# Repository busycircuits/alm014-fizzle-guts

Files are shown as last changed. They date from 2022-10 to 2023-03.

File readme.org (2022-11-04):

* ALM014 FIZZLE GUTS

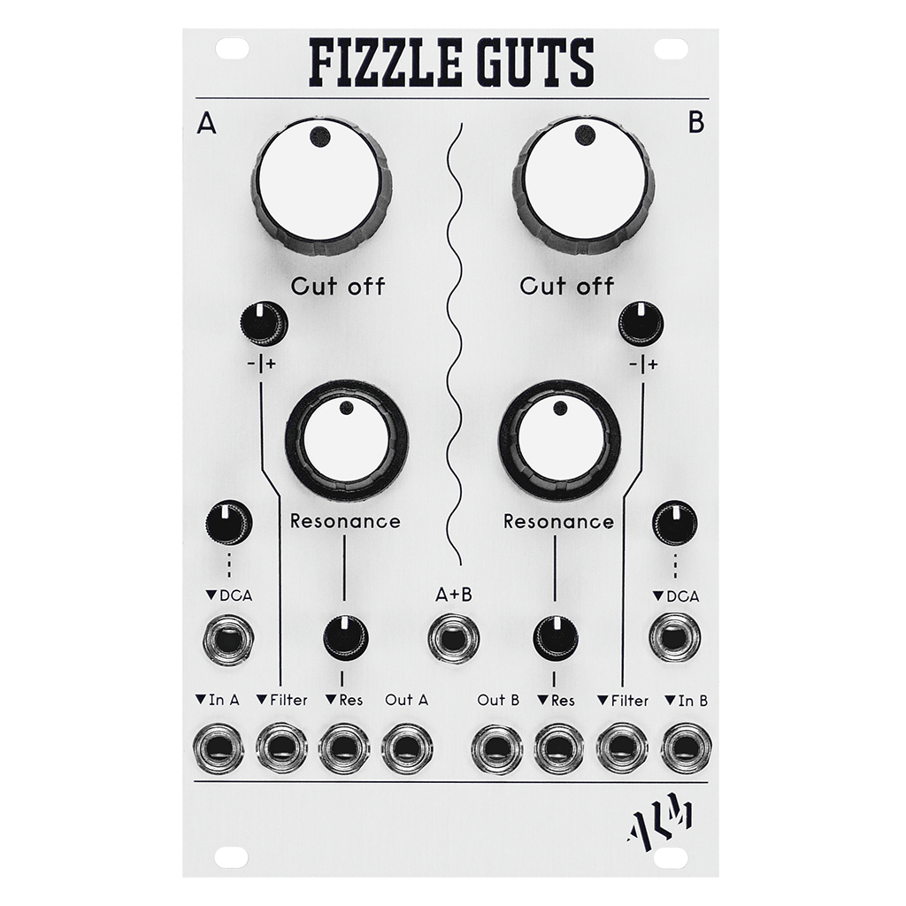
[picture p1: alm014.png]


** Introduction

The ALM Busy Circuits 'Fizzle guts' is a Eurorack dual low pass filter
and VCA that uses a 'donor' filter MB87186 chip from a Casio FZ1
sampler. It was originally designed in 2014 as a fun side project and
only approx 30 of the original units were made. With no plans to make
any more, we have open sourced the pcb design files (eagle), avr
microcontroller code and a basic panel design so others can make there
own and add customisations and/or improvements.

A built module features two filter cores A & B with voltage and direct
controlled resonance and cut off as well as a 'DCA' (a digital
controlled vca). There is also a mix output. Expect a weird murky
sounding filter which can squeek and blip when modulated but can
really squelch up nice.

You will need a donor 'MB87186' IC desolded from a real FZ1 or FZ1M
synth. They each contain 4 and the IC is usually marked 'FM1' with a
date code below. The IC then connects to the DIL socket on the rear of
the module.

For more information on the MB87186 (and from what much of the code
was based on) see http://www.buchty.net/casio/dcf.html

*PLEASE NOTE EVERYTHING IS PROVIDED AS IS. WE ARE UNABLE PROVIDE ANY SUPPORT TO ANYONE ATTEMPTING TO USE THESE FILES*

** Building and flashing the firmware

You'll need a basic 'usbtiny' AVR programmer.

You'll need to install avr-gcc and avrdude.

/(On mac using brew..)/
#+BEGIN_SRC
brew tap osx-cross/avr
brew install avr-gcc
brew install avrdude
#+END_SRC

Type 'make' in the firmare/ directory to compile the source code and
then run './flash.sh' (with your programmer connected) to program the
Fizzle.

** License

Code: MIT license.

Hardware: cc-by-sa-3.0

** Guidelines for derivative works

*ALM is a registered trademark.*

The name "ALM" should not be used on any of the derivative works you create from these files.

We kindly ask to do not name any derivatives 'FIZZLE GUTS' but give it a new name.

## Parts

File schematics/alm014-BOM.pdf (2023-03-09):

### FZ-FILTER-REV003 Passives + IC’s BOM

Qty | Parts | Value | Device | Package | Description | MF
1 | R38 | 1M | RESISTOR0603 | R0603
14 | R1, R3, R7, R10, R12, R14, R22, R32, R33, R34, R36, R46, R9, R16 | 100K | RESISTOR0603 | R0603
15 | R15, R17, R18, R19, R20, R23, R25, R27, R30, R35, R53, R39, R11, R29, R31 | 49.9k | RESISTOR0603 | R0603
4 | R6, R48, R50, R51 | 33K | RESISTOR0603 | R0603
12 | R2, R4, R5, R21, R28, R42, R45, R47, R40, R41, R43, R44 | 10K | RESISTOR0603 | R0603
3 | R8, R13, R49 | 1K | RESISTOR0603 | R0603
2 | R26, R37 | 2.2K | RESISTOR0603 | R0603
13 | C3, C7, C8, C13, C14, C15, C17, C18, C22, C28, C29, C31, C41 | 100n | CAPACITOR0603 | C0603
4 | C11, C16, C23, C24 | 10n | CAPACITOR0603 | C0603
2 | C21, C9 | 1n | CAPACITOR0603 | C0603
2 | C6, C27 | 47pf | CAPACITOR0603 | C0603
2 | C19, C20 | 20pf | CAPACITOR0603 | C0603
5 | C1, C2, C5, C12, C26 | 10uf / 25V | CPOL-EUB | PANASONIC_B | POLARIZED CAPACITOR, European symbol | Panasonic EEEHA1E100WR (or equiv)
2 | C4, C25 | 1uf / 25V | CPOL-EUB | PANASONIC_B | POLARIZED CAPACITOR, European symbol | Panasonic EEE1HA010SR (or equiv)
2 | D3, D13 | BAT54S | BAT54S | SOT23 | Schottky Diodes | BAT45S
2 | D1, D2 | RS 301-906 | DIODESMB | SMB-DIODE | Diode | Vishay VS-MBRS130LTRPBF (or similar)
1 | QF1 | 3.58Mhz | | | 3.58Mhz Resonator | Murata CSTLS3M58G56-B0
5 | IC1, IC2, IC5, IC7, IC8 | TL072D | TL072D | SO08 | OP AMP | TL072
1 | IC3 | MCP6004 | MCP6004 | SO14 | OP AMP | MCP6004
1 | IC6 | ATMEGA644A | ATMEGA644A | TQFP44 | MCU | Mouser 556-ATMEGA644A-AU
1 | U1 | SN74LVC2G14DBV | SN74LVC2G14DBV | SOT23-6 | DUAL SCHMITT-TRIGGER INVERTER | Mouser 595-SN74LVC2G14DBVR
1 | U3 | 7805 | VREG-7805-DPAK2 | VREG-7805-DPAK2 | | Mouser L7805CD2T-TR
1 | Y2 | 8M10AHC49T | 8M10AHC49T | HC49U | 20Mhz Crystal | Mouser 420-200-20-5PX

All caps at least 16v. All resistors 1% at least 0.1 watt

1

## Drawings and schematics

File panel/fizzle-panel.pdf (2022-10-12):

A B

# FIZZLE GUTS

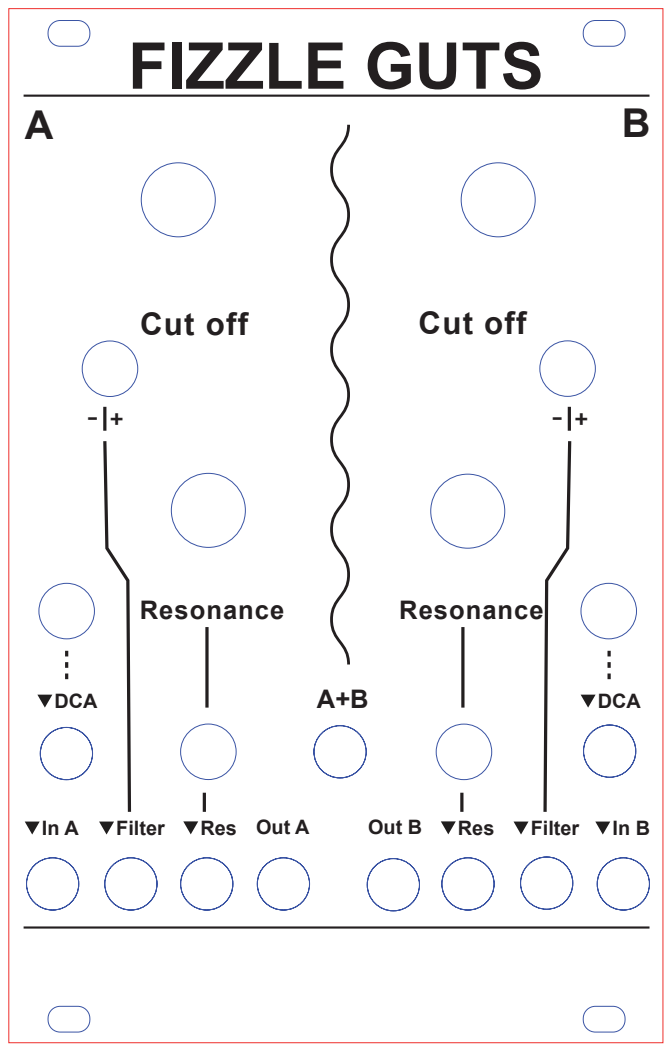
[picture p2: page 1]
Filter; Filter In B; DCA; Res Out A; Out B; Res; Cut off; Resonance

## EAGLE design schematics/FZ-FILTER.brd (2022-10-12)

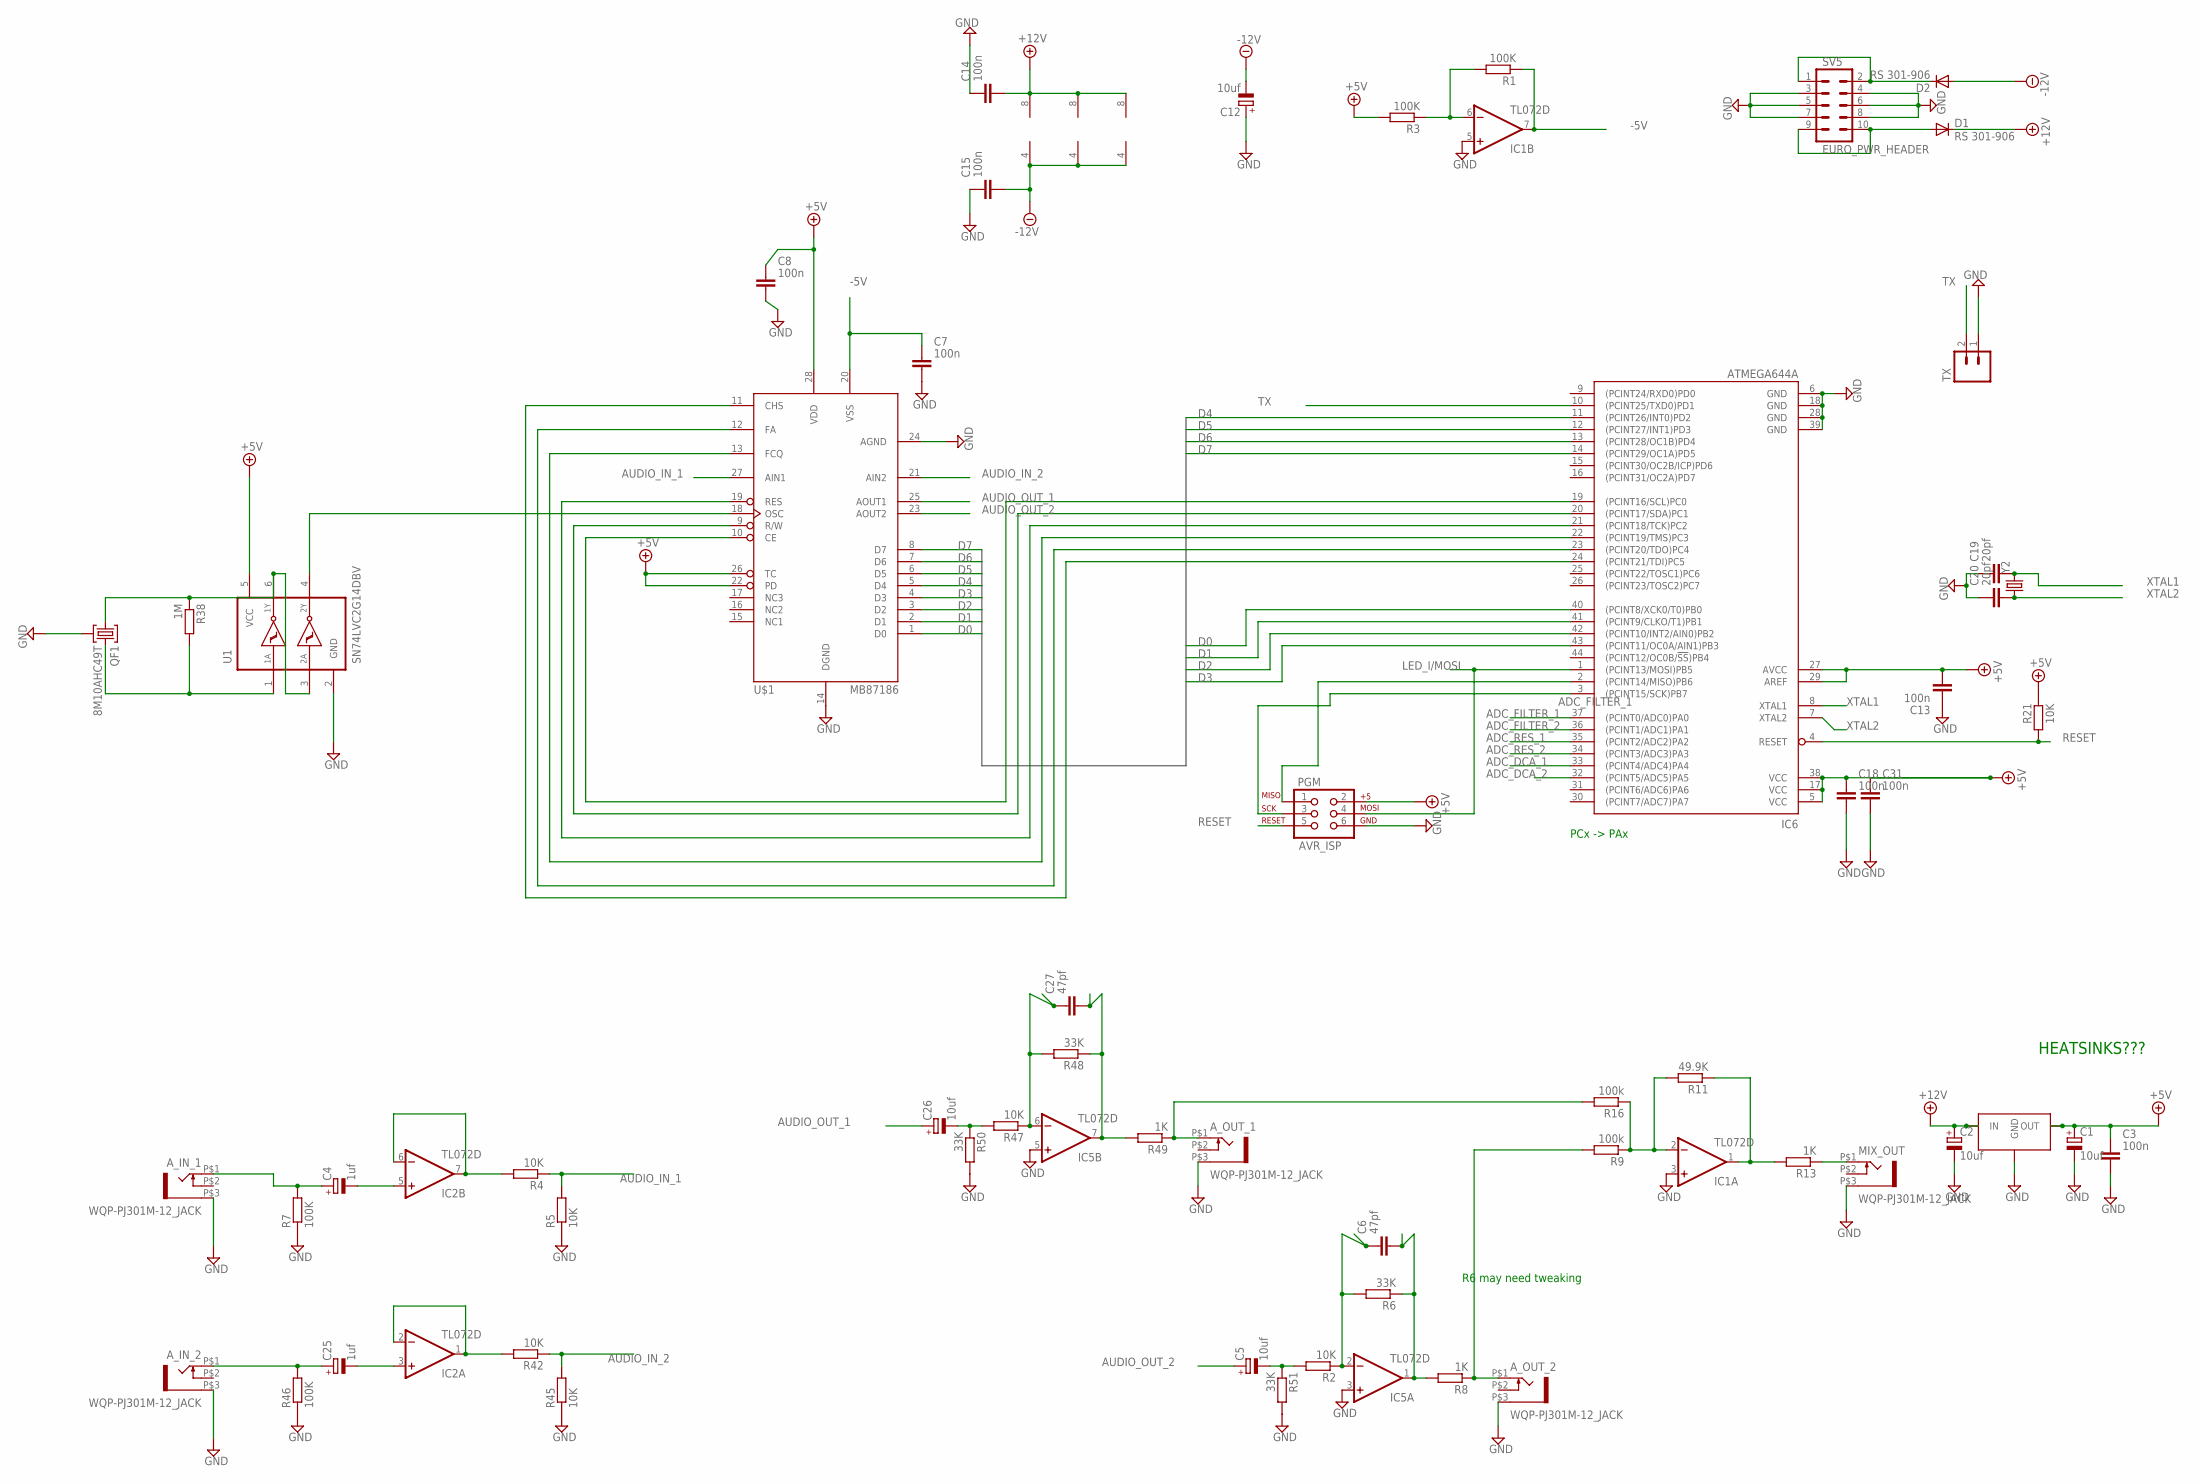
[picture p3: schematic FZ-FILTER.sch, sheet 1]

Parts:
A_IN_1, A_IN_2: WQP-PJ301M-12_JACK
A_OUT_1, A_OUT_2: WQP-PJ301M-12_JACK
C1, C2, C5, C12, C26: 10uf; PANASONIC_B
C3, C7, C8, C13, C14, C15, C18, C31: 100n; C0603
C4, C25: 1uf; PANASONIC_B
C6, C27: 47pf; C0603
C19, C20: 20pf; C0603
D1, D2: RS 301-906; SMB-DIODE
IC1, IC2, IC5: TL072D; SO08
IC6: ATMEGA644A; TQFP44
MIX_OUT: WQP-PJ301M-12_JACK
PGM: AVR_ISP; 2X3
QF1: 8M10AHC49T; HC49U
R1, R3, R7, R46: 100K; R0603
R2, R4, R5, R21, R42, R45, R47: 10K; R0603
R6, R48, R50, R51: 33K; R0603
R8, R13, R49: 1K; R0603
R9, R16: 100k; R0603
R11: 49.9K; R0603
R38: 1M; R0603
SV5: EURO_PWR_HEADER
TX: M02PTH; 1X02
U1: SN74LVC2G14DBV; SOT23-6
U3: 7805; VREG-7805-DPAK2
U$1: MB87186; DIP28
Y2: CRYSTALSMD; HC49UP

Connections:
+5V: C1.+, C3.1, C8.1, C13.2, C18.1, C31.1, IC6.5 (VCC), IC6.17 (VCC), IC6.27 (AVCC), IC6.29 (AREF), IC6.38 (VCC), PGM.2, R3.2, R21.2, U1.5 (VCC), U3.VOUT (OUT), U$1.22 (PD), U$1.26 (TC), U$1.28 (VDD); also elsewhere on the board
+12V: C2.+, C14.2, D1.C, IC1.8 (V+), IC2.8 (V+), IC5.8 (V+), U3.VIN (IN); also elsewhere on the board
-5V: C7.1, IC1.7 (OUT), R1.1, U$1.20 (VSS); also elsewhere on the board
-12V: C12.-, C15.2, D2.A, IC1.4 (V-), IC2.4 (V-), IC5.4 (V-); also elsewhere on the board
ADC_DCA_1: IC6.33 ((PCINT4/ADC4)PA4); also elsewhere on the board
ADC_DCA_2: IC6.32 ((PCINT5/ADC5)PA5); also elsewhere on the board
ADC_FILTER_1: IC6.37 ((PCINT0/ADC0)PA0); also elsewhere on the board
ADC_FILTER_2: IC6.36 ((PCINT1/ADC1)PA1); also elsewhere on the board
ADC_MISO: IC6.2 ((PCINT14/MISO)PB6), PGM.1
ADC_RES_1: IC6.35 ((PCINT2/ADC2)PA2); also elsewhere on the board
ADC_RES_2: IC6.34 ((PCINT3/ADC3)PA3); also elsewhere on the board
ADC_SCK: IC6.3 ((PCINT15/SCK)PB7), PGM.3
AUDIO_IN_1: R4.1, R5.2, U$1.27 (AIN1)
AUDIO_IN_2: R42.1, R45.2, U$1.21 (AIN2)
AUDIO_OUT_1: C26.+, U$1.25 (AOUT1)
AUDIO_OUT_2: C5.+, U$1.23 (AOUT2)
D0: IC6.40 ((PCINT8/XCK0/T0)PB0), U$1.1 (D0)
D1: IC6.41 ((PCINT9/CLKO/T1)PB1), U$1.2 (D1)
D2: IC6.42 ((PCINT10/INT2/AIN0)PB2), U$1.3 (D2)
D3: IC6.43 ((PCINT11/OC0A/AIN1)PB3), U$1.4 (D3)
D4: IC6.11 ((PCINT26/INT0)PD2), U$1.5 (D4)
D5: IC6.12 ((PCINT27/INT1)PD3), U$1.6 (D5)
D6: IC6.13 ((PCINT28/OC1B)PD4), U$1.7 (D6)
D7: IC6.14 ((PCINT29/OC1A)PD5), U$1.8 (D7)
GND: A_IN_1.P$3 (1), A_IN_2.P$3 (1), A_OUT_1.P$3 (1), A_OUT_2.P$3 (1), C1.-, C2.-, C3.2, C7.2, C8.2, C12.+, C13.1, C14.1, C15.1, C18.2, C19.1, C20.1, C31.2, IC1.3 (+IN), IC1.5 (+IN), IC5.3 (+IN), IC5.5 (+IN), IC6.6 (GND), IC6.18 (GND), IC6.28 (GND), IC6.39 (GND), MIX_OUT.P$3 (1), PGM.6, QF1.2, R5.1, R7.1, R45.1, R46.1, R50.2, R51.2, SV5.3, SV5.4, SV5.5, SV5.6, SV5.7, SV5.8, TX.1, U1.2 (GND), U3.GND, U$1.14 (DGND), U$1.24 (AGND); also elsewhere on the board
LED_I/MOSI: IC6.1 ((PCINT13/MOSI)PB5), PGM.4
unnamed: D2.C, SV5.1, SV5.2
unnamed: IC1.6 (-IN), R1.2, R3.1
unnamed: D1.A, SV5.9, SV5.10
unnamed: IC2.6 (-IN), IC2.7 (OUT), R4.2
unnamed: C6.1, IC5.2 (-IN), R2.1, R6.2
unnamed: C6.2, IC5.1 (OUT), R6.1, R8.2
unnamed: C5.-, R2.2, R51.1
unnamed: A_OUT_1.P$1 (2), R16.2, R49.1
unnamed: IC1.2 (-IN), R9.1, R11.2, R16.1
unnamed: IC1.1 (OUT), R11.1, R13.2
unnamed: A_OUT_2.P$1 (2), R8.1, R9.2
unnamed: C4.-, IC2.5 (+IN)
unnamed: A_IN_1.P$1 (2), C4.+, R7.2
unnamed: C25.-, IC2.3 (+IN)
unnamed: IC2.1 (OUT), IC2.2 (-IN), R42.2
unnamed: A_IN_2.P$1 (2), C25.+, R46.2
unnamed: C27.1, IC5.6 (-IN), R47.1, R48.2
unnamed: C27.2, IC5.7 (OUT), R48.1, R49.2
unnamed: C26.-, R47.2, R50.1
unnamed: MIX_OUT.P$1 (2), R13.1
unnamed: IC6.19 ((PCINT16/SCL)PC0), U$1.10 (CE)
unnamed: IC6.20 ((PCINT17/SDA)PC1), U$1.9 (R/W)
unnamed: IC6.21 ((PCINT18/TCK)PC2), U$1.19 (RES)
unnamed: IC6.22 ((PCINT19/TMS)PC3), U$1.13 (FCQ)
unnamed: IC6.23 ((PCINT20/TDO)PC4), U$1.12 (FA)
unnamed: IC6.24 ((PCINT21/TDI)PC5), U$1.11 (CHS)
unnamed: U1.4 (2Y), U$1.18 (OSC)
unnamed: QF1.1, R38.1, U1.3 (2A), U1.6 (1Y)
unnamed: QF1.3, R38.2, U1.1 (1A)
RESET: IC6.4 (RESET), PGM.5, R21.1
TX: IC6.10 ((PCINT25/TXD0)PD1), TX.2
XTAL1: C19.2, IC6.8 (XTAL1), Y2.2
XTAL2: C20.2, IC6.7 (XTAL2), Y2.1

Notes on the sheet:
PCx -> PAx
HEATSINKS???
R6 may need tweaking

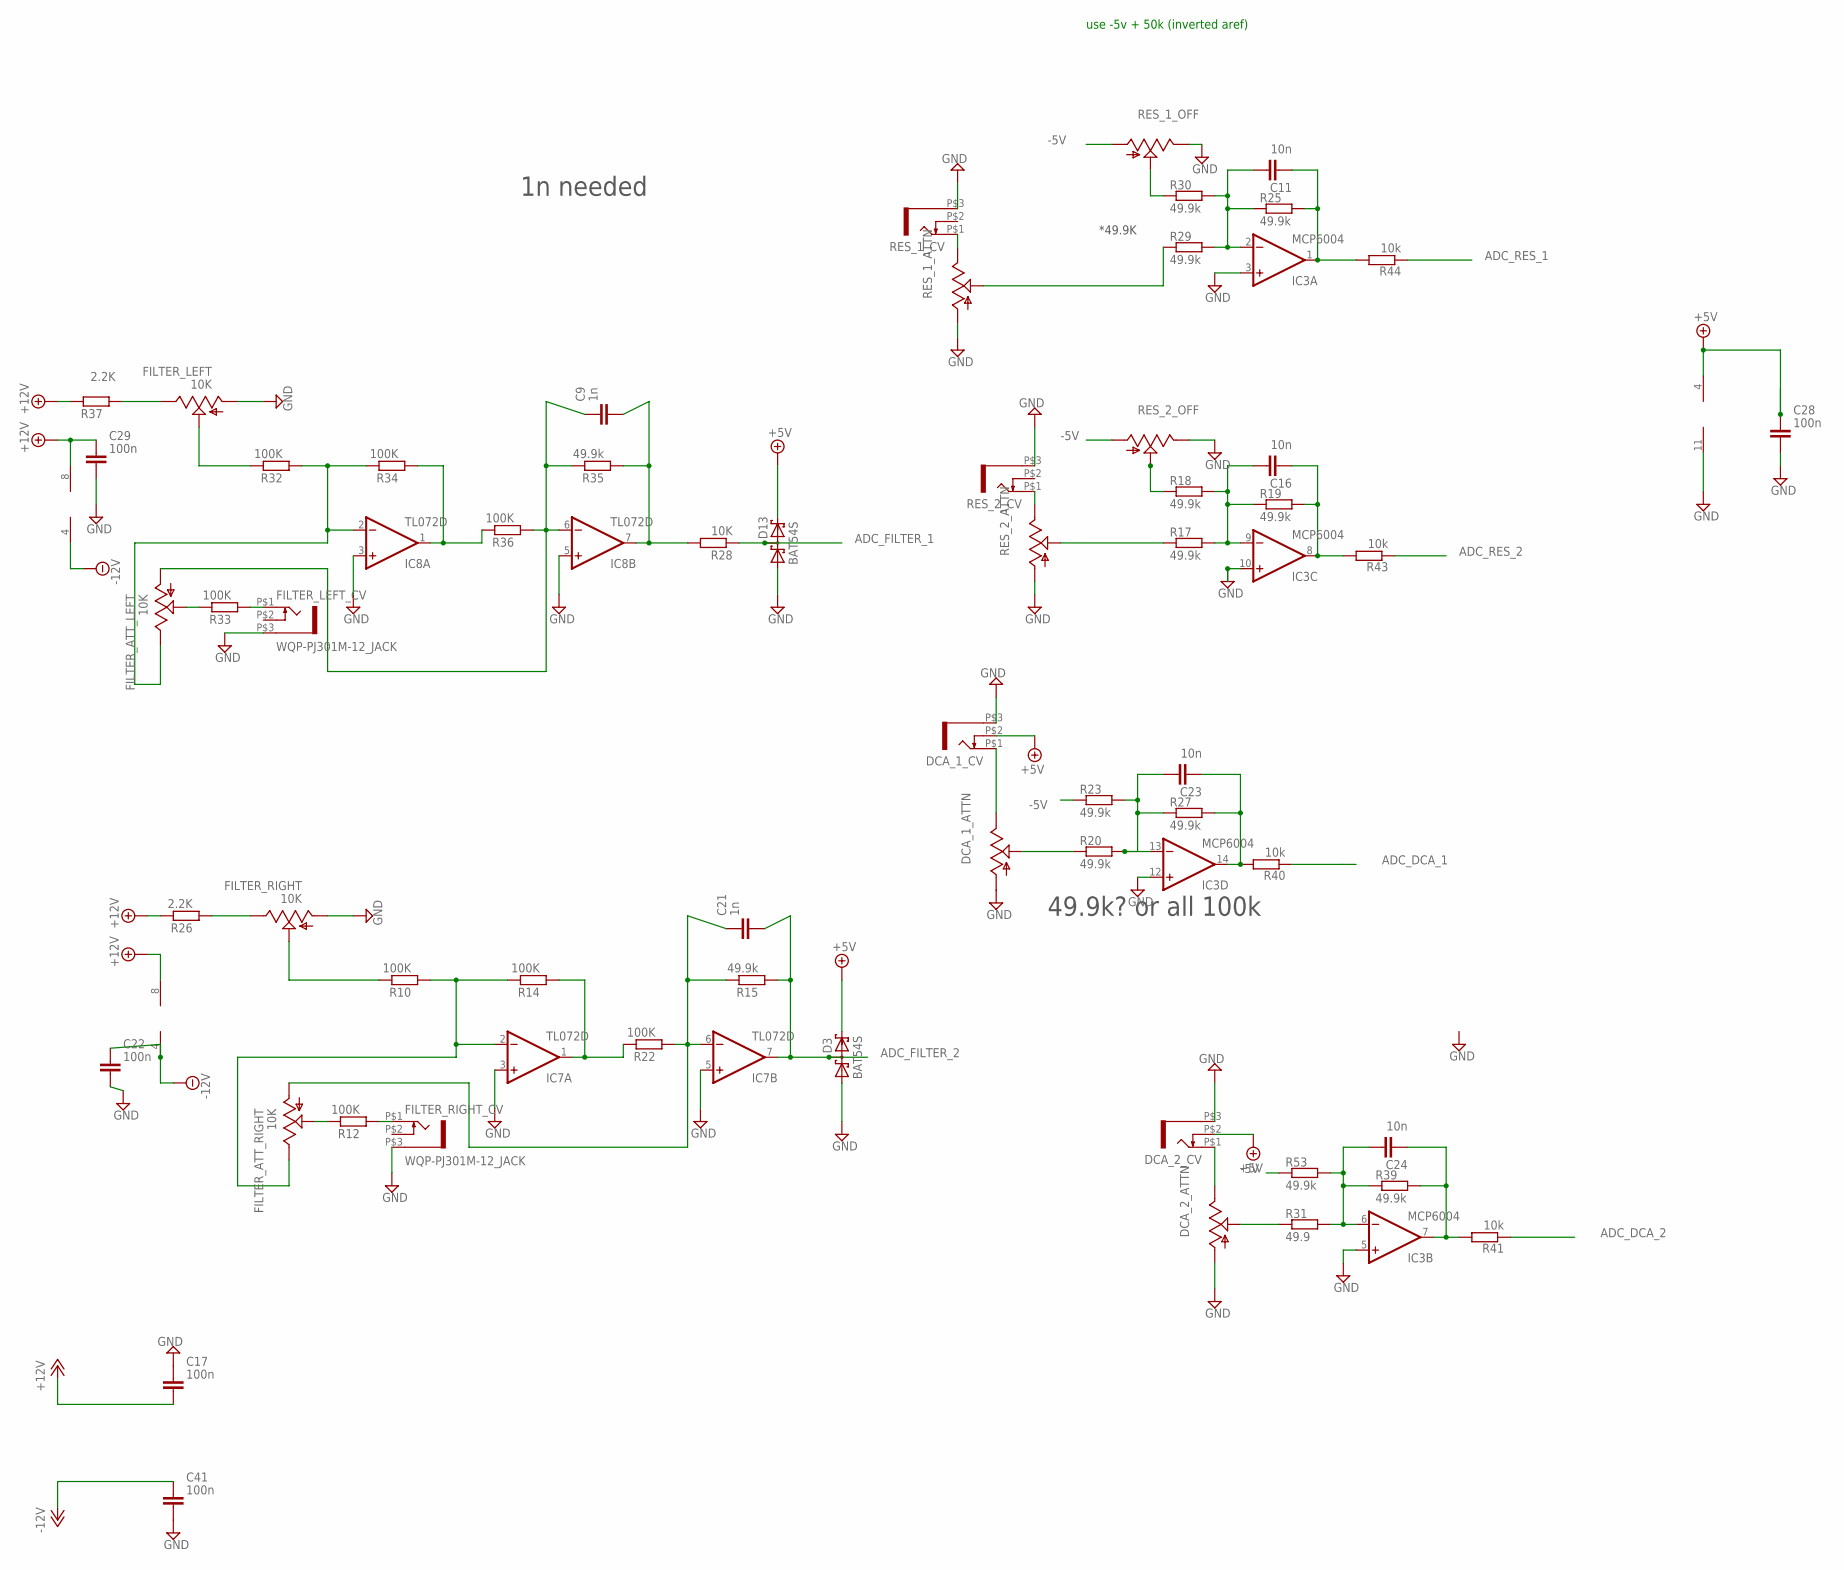
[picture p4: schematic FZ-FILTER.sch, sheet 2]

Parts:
C9, C21: 1n; C0603
C11, C16, C23, C24: 10n; C0603
C17, C22, C28, C29, C41: 100n; C0603
D3, D13: BAT54S; SOT23
DCA_1_ATTN, DCA_2_ATTN: ALPHA-9MMA; EVUF
DCA_1_CV, DCA_2_CV: WQP-PJ301M-12_JACK
FILTER_ATT_LEFT: 10K; EVUF
FILTER_ATT_RIGHT: 10K; EVUF
FILTER_LEFT: 10K; EVUF
FILTER_LEFT_CV: WQP-PJ301M-12_JACK
FILTER_RIGHT: 10K; EVUF
FILTER_RIGHT_CV: WQP-PJ301M-12_JACK
IC3: MCP6004; SO14
IC7, IC8: TL072D; SO08
R10, R12, R14, R22, R32, R33, R34, R36: 100K; R0603
R15, R17, R18, R19, R20, R23, R25, R27, R29, R30, R35, R39, R53: 49.9k; R0603
R26, R37: 2.2K; R0603
R28: 10K; R0603
R31: 49.9; R0603
R40, R41, R43, R44: 10k; R0603
RES_1_ATTN, RES_1_OFF, RES_2_ATTN, RES_2_OFF: ALPHA-9MMA; EVUF
RES_1_CV, RES_2_CV: WQP-PJ301M-12_JACK

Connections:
+5V: C28.1, D3.2 (C2), D13.2 (C2), DCA_1_CV.P$2 (3), DCA_2_CV.P$2 (3), IC3.4 (V+); also elsewhere on the board
+12V: C17.2, C29.1, IC7.8 (V+), IC8.8 (V+), R26.2, R37.2; also elsewhere on the board
-5V: R23.1, R53.1, RES_1_OFF.1 (A), RES_2_OFF.1 (A); also elsewhere on the board
-12V: C22.1, C41.1, IC7.4 (V-), IC8.4 (V-); also elsewhere on the board
ADC_DCA_1: R40.1; also elsewhere on the board
ADC_DCA_2: R41.1; also elsewhere on the board
ADC_FILTER_1: D13.3 (C1A2), R28.1; also elsewhere on the board
ADC_FILTER_2: C21.2, D3.3 (C1A2), IC7.7 (OUT), R15.1; also elsewhere on the board
ADC_RES_1: R44.1; also elsewhere on the board
ADC_RES_2: R43.1; also elsewhere on the board
GND: C17.1, C22.2, C28.2, C29.2, C41.2, D3.1 (A1), D13.1 (A1), DCA_1_ATTN.1 (A), DCA_1_CV.P$3 (1), DCA_2_ATTN.1 (A), DCA_2_CV.P$3 (1), FILTER_LEFT.1 (A), FILTER_LEFT_CV.P$3 (1), FILTER_RIGHT.1 (A), FILTER_RIGHT_CV.P$3 (1), IC3.3 (+IN), IC3.5 (+IN), IC3.10 (+IN), IC3.11 (V-), IC3.12 (+IN), IC7.3 (+IN), IC7.5 (+IN), IC8.3 (+IN), IC8.5 (+IN), RES_1_ATTN.1 (A), RES_1_CV.P$3 (1), RES_1_OFF.3 (E), RES_2_ATTN.1 (A), RES_2_CV.P$3 (1), RES_2_OFF.3 (E); also elsewhere on the board
I7: C9.2, IC8.7 (OUT), R28.2, R35.1
unnamed: RES_1_ATTN.3 (E), RES_1_CV.P$1 (2)
unnamed: R30.1, RES_1_OFF.2 (S)
unnamed: C24.1, IC3.6 (-IN), R31.2, R39.1, R53.2
unnamed: C11.2, IC3.1 (OUT), R25.2, R44.2
unnamed: R29.1, RES_1_ATTN.2 (S)
unnamed: DCA_1_ATTN.3 (E), DCA_1_CV.P$1 (2)
unnamed: C16.1, IC3.9 (-IN), R17.2, R18.2, R19.1
unnamed: R18.1, RES_2_OFF.2 (S)
unnamed: RES_2_ATTN.3 (E), RES_2_CV.P$1 (2)
unnamed: C23.1, IC3.13 (-IN), R20.2, R23.2, R27.1
unnamed: DCA_1_ATTN.2 (S), R20.1
unnamed: DCA_2_ATTN.2 (S), R31.1
unnamed: C16.2, IC3.8 (OUT), R19.2, R43.2
unnamed: DCA_2_ATTN.3 (E), DCA_2_CV.P$1 (2)
unnamed: FILTER_RIGHT.2 (S), R10.2
unnamed: FILTER_ATT_RIGHT.3 (E), IC7.2 (-IN), R10.1, R14.2
unnamed: C11.1, IC3.2 (-IN), R25.1, R29.2, R30.2
unnamed: FILTER_RIGHT_CV.P$1 (2), R12.1
unnamed: FILTER_ATT_RIGHT.2 (S), R12.2
unnamed: IC7.1 (OUT), R14.1, R22.2
unnamed: C21.1, FILTER_ATT_RIGHT.1 (A), IC7.6 (-IN), R15.2, R22.1
unnamed: FILTER_RIGHT.3 (E), R26.1
unnamed: FILTER_LEFT.2 (S), R32.2
unnamed: FILTER_ATT_LEFT.3 (E), IC8.2 (-IN), R32.1, R34.2
unnamed: FILTER_LEFT_CV.P$1 (2), R33.1
unnamed: IC8.1 (OUT), R34.1, R36.2
unnamed: C9.1, FILTER_ATT_LEFT.1 (A), IC8.6 (-IN), R35.2, R36.1
unnamed: FILTER_LEFT.3 (E), R37.1
unnamed: FILTER_ATT_LEFT.2 (S), R33.2
unnamed: R17.1, RES_2_ATTN.2 (S)
REL1_ADC: C23.2, IC3.14 (OUT), R27.2, R40.2
REL2_ADC: C24.2, IC3.7 (OUT), R39.2, R41.2

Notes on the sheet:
use -5v + 50k (inverted aref)
49.9k? or all 100k
1n needed
*49.9K

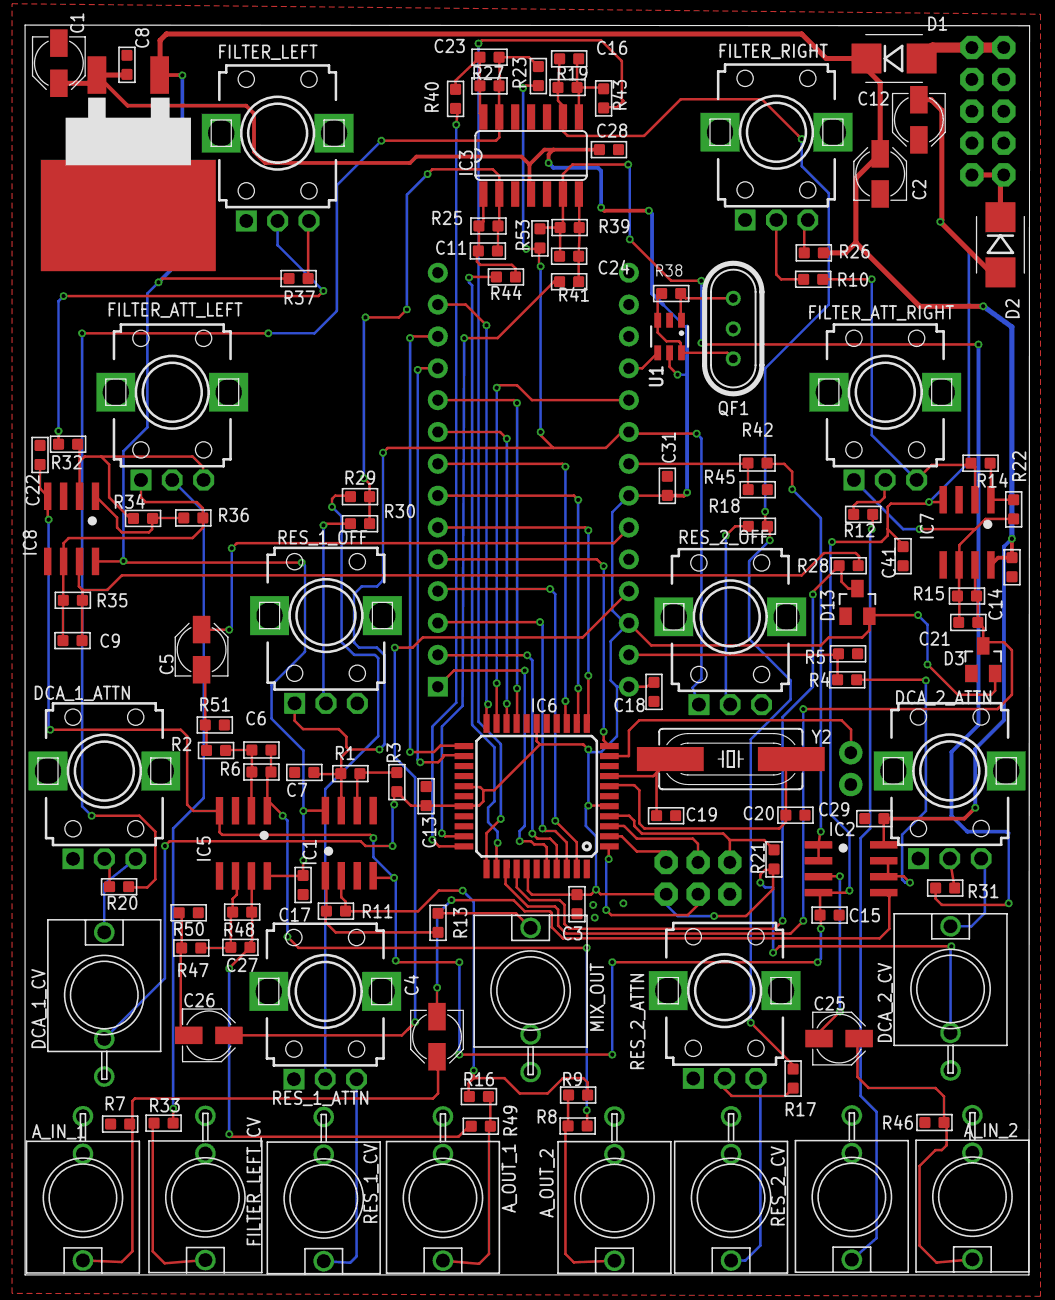
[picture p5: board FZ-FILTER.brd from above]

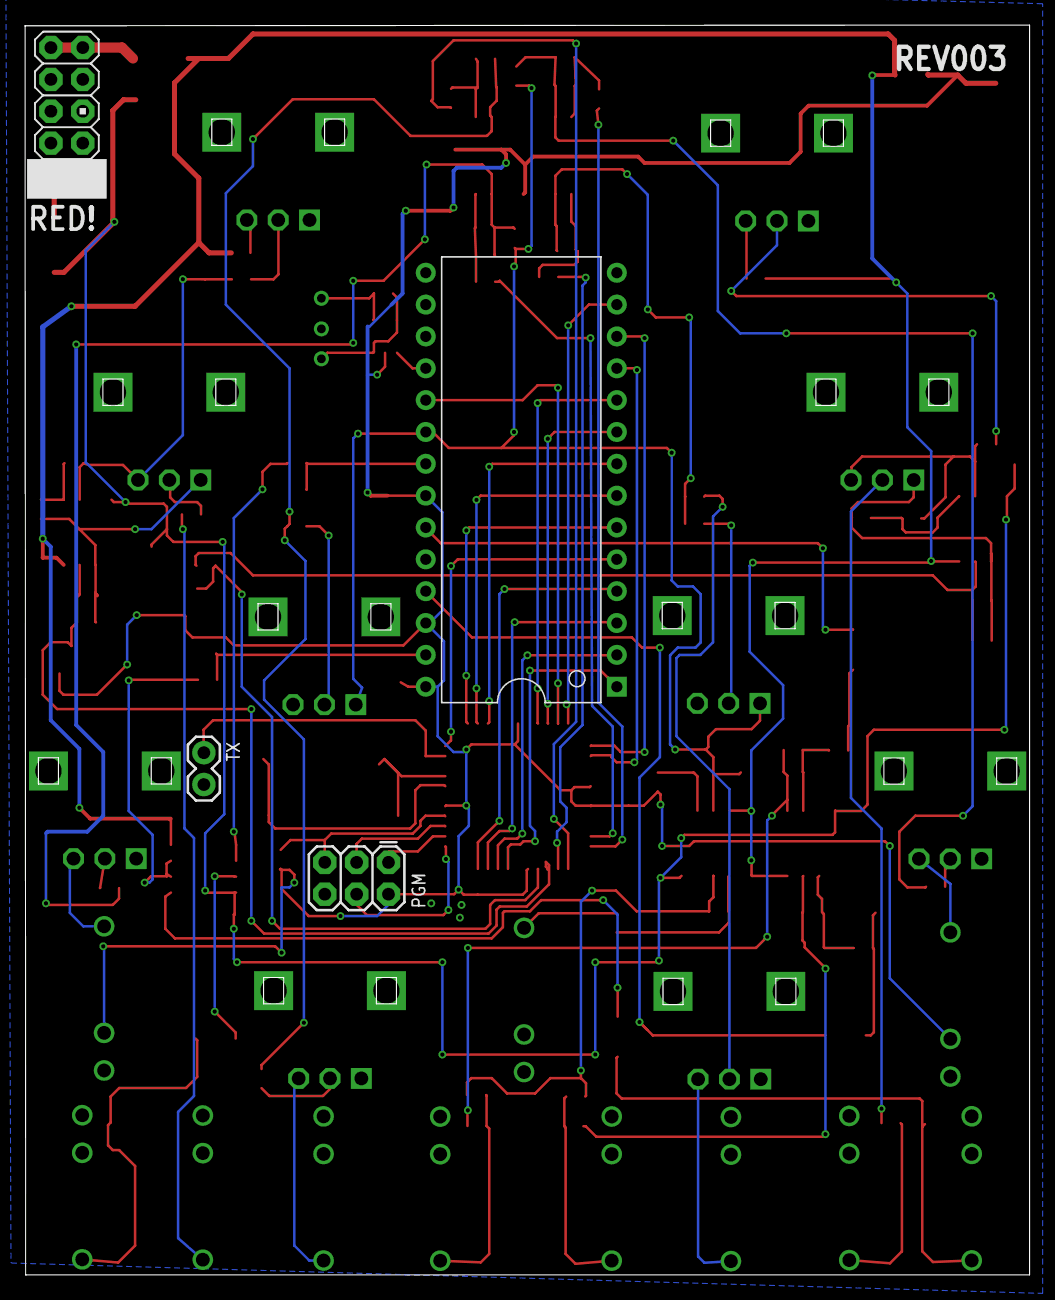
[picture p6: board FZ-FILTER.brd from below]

Board: 2 copper layers, 80.1 x 99.7 mm, 122 parts (5 on the bottom side), 92 nets.

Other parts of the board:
U$2: LOGO_WEEE

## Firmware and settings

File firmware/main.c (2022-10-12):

/*
*   ALM014 'FIZZLE GUTS' firmware 
*   
*   Copyright (c) 2014 ALM Co Ltd
*   
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
*/
#include "uu.h"
#include <avr/pgmspace.h>
#include <util/delay.h>


#define PIN_FZ_D0 PIN_B0
#define PIN_FZ_D1 PIN_B1
#define PIN_FZ_D2 PIN_B2
#define PIN_FZ_D3 PIN_B3
#define PIN_FZ_D4 PIN_D2
#define PIN_FZ_D5 PIN_D3
#define PIN_FZ_D6 PIN_D4
#define PIN_FZ_D7 PIN_D5

#define PIN_FZ_CHS PIN_C5
#define PIN_FZ_FA  PIN_C4
#define PIN_FZ_FCQ PIN_C3
#define PIN_FZ_RES PIN_C2
#define PIN_FZ_RW  PIN_C1
#define PIN_FZ_CE  PIN_C0

#define ADC_CHAN_FILTER_0 0
#define ADC_CHAN_FILTER_1 1
#define ADC_CHAN_RES_0 2
#define ADC_CHAN_RES_1 3
#define ADC_CHAN_DCA_0 4
#define ADC_CHAN_DCA_1 5


void cycle ();

int analog_read(uint8_t chan)
{
  uint8_t low, high;
  
  /* switch to ADMUX for (1<<6) - AVcc with external capacitor on AREF pin  */
  ADMUX = chan; // AREF, Internal Vref turned off  & chan 0 

  _delay_us(100); /* wait for mux to settle */
  
  ADCSRA = (1<<ADEN) | (1<<ADPS2) | (1<<ADPS1);
  /* Start conversion */
  ADCSRA |= (1<<ADSC);
  /* Wait.. */
  while (uu_bit_is_set(ADCSRA, ADSC));
  /* Collect */
  low  = ADCL;
  high = ADCH;

  return (high << 8) | low;
}

void FZ_poke (uint8_t data) 
{
  uu_pin_digital_write (PIN_FZ_RW, LOW); /* chip write enable */
  
  uu_pin_digital_write( PIN_FZ_D0, (data & 0x1));
  uu_pin_digital_write( PIN_FZ_D1, ((data>>1) & 0x1));
  uu_pin_digital_write( PIN_FZ_D2, ((data>>2) & 0x1));
  uu_pin_digital_write( PIN_FZ_D3, ((data>>3) & 0x1));
  uu_pin_digital_write( PIN_FZ_D4, ((data>>4) & 0x1));
  uu_pin_digital_write( PIN_FZ_D5, ((data>>5) & 0x1));
  uu_pin_digital_write( PIN_FZ_D6, ((data>>6) & 0x1));
  uu_pin_digital_write( PIN_FZ_D7, ((data>>7) & 0x1));

  _delay_us(10);

  uu_pin_digital_write (PIN_FZ_RW, HIGH); /* chip write disable */
}  


void setup () 
{
  int c, i = 0;

  uu_init(0);

  /* ADC's */
  uu_pin_mode( PIN_A0, INPUT);
  uu_pin_mode( PIN_A1, INPUT);
  uu_pin_mode( PIN_A2, INPUT);
  uu_pin_mode( PIN_A3, INPUT);
  uu_pin_mode( PIN_A4, INPUT);
  uu_pin_mode( PIN_A5, INPUT);
  
  uu_pin_mode( PIN_FZ_D0, OUTPUT);
  uu_pin_mode( PIN_FZ_D1, OUTPUT);
  uu_pin_mode( PIN_FZ_D2, OUTPUT);
  uu_pin_mode( PIN_FZ_D3, OUTPUT);
  uu_pin_mode( PIN_FZ_D4, OUTPUT);
  uu_pin_mode( PIN_FZ_D5, OUTPUT);
  uu_pin_mode( PIN_FZ_D6, OUTPUT);
  uu_pin_mode( PIN_FZ_D7, OUTPUT);
  
  uu_pin_mode( PIN_FZ_CHS, OUTPUT);
  uu_pin_mode( PIN_FZ_FA, OUTPUT);
  uu_pin_mode( PIN_FZ_FCQ, OUTPUT);
  uu_pin_mode( PIN_FZ_RES, OUTPUT);
  uu_pin_mode( PIN_FZ_RW, OUTPUT);
  uu_pin_mode( PIN_FZ_CE, OUTPUT);
  
  uu_pin_digital_write (PIN_FZ_CE, LOW); /* chip enable */

  uu_pin_digital_write (PIN_FZ_RW, HIGH); /* chip write disable */
  
  uu_pin_digital_write (PIN_FZ_RES, LOW); /* Reset - low active */
  uu_delay_ms(100);
  uu_pin_digital_write (PIN_FZ_RES, HIGH); /* Reset - low active */
  

  uu_pin_digital_write (PIN_FZ_CHS, HIGH); /* channel 0 - channel select */

  uu_pin_digital_write (PIN_FZ_FA, LOW); /* gain - 10 bit? */
  uu_pin_digital_write (PIN_FZ_FCQ, LOW); /* ??? */

  FZ_poke (0xff);  		/* Gain - all 8 bits */

  uu_pin_digital_write (PIN_FZ_FCQ, HIGH); /* gain */

  FZ_poke (0xff);  		/* Gain - just upper 2 bits */
  
}

void cycle () 
{
  static int prev_dca[2], prev_cutoff[2], prev_rez[2], hyst_dca[2], hyst_cutoff[2], hyst_rez[2];;

  int dca, cutoff = 0, rez = 0, i = 0;

  /* Note 6 over 4 as seems to be much more noise on ADC */
#define DO_HYST(c,p) if ( ((c) > (p) + 4) || ((c) < (p) - 4) ) { (p) = (c); } else { (c) = (p); }

  for (i=0; i<2; i++)
    {
      uu_pin_digital_write (PIN_FZ_CHS, !i); /* channel select */
     
      dca = 0x3ff - analog_read(ADC_CHAN_DCA_0+i);

      DO_HYST(dca, hyst_dca[i]);
  
      if (dca != prev_dca[i])
	{
	  uu_pin_digital_write (PIN_FZ_FA, LOW); /* gain - 10 bit? */
	  uu_pin_digital_write (PIN_FZ_FCQ, HIGH); /* gain */

	  /* 3 for high gain not to zero*/
	  /* 1 for for low gain */
	  
	  FZ_poke (dca >> 8);  		/* Gain - just upper 2 bits - do first*/
	  uu_pin_digital_write (PIN_FZ_FA, LOW); /* gain - 10 bit? */
	  uu_pin_digital_write (PIN_FZ_FCQ, LOW); /* ??? */
	  FZ_poke (dca & 0xff);
      
	  prev_dca[i] = dca;
	}

      //rez = 0xf - (analog_read(ADC_CHAN_RES_0) >> 6); /* 4 bit? */
      rez = (0x3ff - (analog_read(ADC_CHAN_RES_0+i))); /* 4 bit? */

      DO_HYST(rez, hyst_rez[i]);
      
      if (rez != prev_rez[i])
	{
	  uu_pin_digital_write (PIN_FZ_FA, HIGH); /* High DCF control */
	  uu_pin_digital_write (PIN_FZ_FCQ, LOW); /* ??? */

	  FZ_poke (rez >> 6);  		/* resonance - MSB? just 4 bits */
	  
	  prev_rez[i] = rez;
	}

      cutoff = analog_read(ADC_CHAN_FILTER_0+i); /* 7 bit? */

      DO_HYST(cutoff, hyst_cutoff[i]);
      
      if (cutoff != prev_cutoff[i])
	{
	  uu_pin_digital_write (PIN_FZ_FA, HIGH);
	  uu_pin_digital_write (PIN_FZ_FCQ, HIGH);

	  FZ_poke (cutoff >> 3);  		/* filter cut off ? */

	  prev_cutoff[i] = cutoff;
	}
    }

}


int main(void)
{
  setup();
  while (TRUE)
    cycle();
}

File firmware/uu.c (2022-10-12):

/*
*   'UU' - Small AVR utility lib
* 
*   Copyright (c) 2014 ALM Co Ltd
*
*   Parts of code based in Wiring/Arduino.h;
*   Copyright (c) 2005-2006 David A. Mellis
*   
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
*/

#include "uu.h"

#ifndef cbi
#define cbi(sfr, bit) (_SFR_BYTE(sfr) &= ~_BV(bit))
#endif
#ifndef sbi
#define sbi(sfr, bit) (_SFR_BYTE(sfr) |= _BV(bit))
#endif

const uint8_t PROGMEM _pin_table_PGM[] = {

#if  defined(__AVR_ATmega328P__) 
  0,
#endif
#if defined(__AVR_AT90USB1286__)
  (int)&PINA,
#endif
#if defined(__AVR_ATmega644P__)
  (int)&PINA,
#endif
  (int)&PINB,
  (int)&PINC,
  (int)&PIND
  /*(int)&PORTE,*/
  /*(int)&PORTF*/
};

void 
uu_delay_ms(uint16_t ms) 
{
  while  (ms)
    {
      _delay_ms(1);
      ms--;
    }
}

void 
uu_delay_us(unsigned int us)
{
	// calling avrlib's delay_us() function with low values (e.g. 1 or
	// 2 microseconds) gives delays longer than desired.
	//delay_us(us);

  // #if F_CPU >= 16000000L
	// for the 16 MHz clock on most Arduino boards

	// for a one-microsecond delay, simply return.  the overhead
	// of the function call yields a delay of approximately 1 1/8 us.
	if (--us == 0)
		return;

	// the following loop takes a quarter of a microsecond (4 cycles)
	// per iteration, so execute it four times for each microsecond of
	// delay requested.
	us <<= 2;

	// account for the time taken in the preceeding commands.
	us -= 2;

	// busy wait
	__asm__ __volatile__ (
		"1: sbiw %0,1" "\n\t" // 2 cycles
		"brne 1b" : "=w" (us) : "0" (us) // 2 cycles
	);
}


void 
uu_pin_mode (Pin pin, bool output)
{
  /* DDRD |= (1<<6); set pin 6 in PORTD to output  */
  /* DDRx &= ~(1<<6); set pin 6 in PORTD to input  */

  if (output)
    *PIN_TO_MODEREG(pin) |= PIN_TO_MASK(pin);
  else
    *PIN_TO_MODEREG(pin) &= ~PIN_TO_MASK(pin);

}

void 
uu_pin_digital_write (Pin pin, bool value)
{
  if (value)
    *PIN_TO_OUTREG(pin) |=  PIN_TO_MASK(pin);
  else
    *PIN_TO_OUTREG(pin) &=~ PIN_TO_MASK(pin);
}

bool 
uu_pin_digital_read (Pin pin)
{
  if ((*PIN_TO_PORTREG(pin) & PIN_TO_MASK(pin)) > 0)
    return HIGH;
  return LOW;
}

void 
uu_pin_shift_out(Pin dataPin, Pin clockPin, uint8_t bitOrder, uint8_t value)
{
  uint8_t mask;
  if (bitOrder == LSBFIRST) 
    {
      for (mask=0x01; mask; mask <<= 1) 
	{
	  uu_pin_digital_write(dataPin, value & mask);
	  uu_pin_digital_write(clockPin, HIGH);
	  uu_pin_digital_write(clockPin, LOW);
	}
    }
  else
    {
      for (mask=0x80; mask; mask >>= 1) 
	{
	  uu_pin_digital_write(dataPin, value & mask);
	  uu_pin_digital_write(clockPin, HIGH);
	  uu_pin_digital_write(clockPin, LOW);
	}
    }
}

uint8_t 
uu_pin_shift_in(Pin dataPin, Pin clockPin, uint8_t bitOrder)
{
  uint8_t mask, value=0;
  if (bitOrder == LSBFIRST) 
    {    
      for (mask=0x01; mask; mask <<= 1) 
	{
	  uu_pin_digital_write(clockPin, HIGH);
	  if (uu_pin_digital_read(dataPin)) value |= mask;
	  uu_pin_digital_write(clockPin, LOW);
	}
    }
  else
    {
      for (mask=0x80; mask; mask >>= 1) 
	{
	  uu_pin_digital_write(clockPin, HIGH);
	  if (uu_pin_digital_read(dataPin)) value |= mask;
	  uu_pin_digital_write(clockPin, LOW);
	}
    }
  return value;
}

void
uu_init(int flags)
{
  sei();
}

void
uu_usart_init()
{
  UBRR0H = (BAUD_PRESCALE >> 8);
  UBRR0L = BAUD_PRESCALE;

  UCSR0C = _BV(UCSZ01) | _BV(UCSZ00); /* 8-bit data */
  /* Just TX */
  UCSR0B |= /*_BV(RXEN0) | */ _BV(TXEN0); 
}

void uu_usart_putc(char c) 
{
  if (c == '\n') 
    {
      uu_usart_putc('\r');
    }

  loop_until_bit_is_set(UCSR0A, UDRE0);
  UDR0 = c;
}

void uu_usart_puts(char *s) 
{
  while (*s) 
    {
      uu_usart_putc(*s);
      s++;
    }
}

/* via https://github.com/sultanqasim/Stellarino/blob/master/stellarino_usart.c */
void uu_usart_puti(long i)
{
  char digs[12], reversed[12];
  uint8_t a = 0, b, neg = 0;

  if (i < 0)
    {
      neg = 1;
      i = -i;
    }

    do
      {
        b = i % 10;
        digs[a] = b + 48;// Convert to digit ASCII
        i /= 10;
        a++;
      } while (i);

    // Reverse the digits into most significant to least significant
    if (neg)
      {
        reversed[0] = '-';
        for (b = 1; b < a + neg; b++)
	  reversed[b] = digs[a - b];
        a += 1;// Extend the length of the string by 1 due to - sign
      }
    else for (b = 0; b < a; b++)
	   reversed[b] = digs[a - b - 1];

    reversed[a] = '\0';
    uu_usart_puts((char *) reversed);
}

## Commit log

2022-10-12 Initial import
    [FZ-FILTER.brd, FZ-FILTER.sch]
2023-03-09 Update BOM with missing QF1 resonator

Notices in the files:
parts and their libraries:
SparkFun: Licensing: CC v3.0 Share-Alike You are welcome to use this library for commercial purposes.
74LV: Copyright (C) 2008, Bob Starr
